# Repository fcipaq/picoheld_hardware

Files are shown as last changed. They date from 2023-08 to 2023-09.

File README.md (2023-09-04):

# Pico Held hardware files

Here you can find the PCB design files, BOM and CPL files, STL files of the case, schematics, components and datasheets for the *Pico Held* - a handheld based on the *Raspberry Pi Pico*.

The hardware project is released under the *Creative Commons NonCommercial license* (BY-NC, non-commercial use).

I am currently still looking for a distributor, so currently the only way to get a *Pico Held* is making your own PCB and case.

## Disclaimer

Please note (as also stated in the liscense): This design and all the files provided come without any warranty. I cannot be held responsible for any damage that might be caused. You build/operate at your own risk.

## Instruction video

This [Youtube](https://youtu.be/bDk0hH1kbgg) video demonstrates how to assemble the *Pico Held*.

## Case

I had the cases printed over at *JLCPCB* (no affiliation) using resin printing with - in my eyes - a very good result.

## PCB production parameters

Some notes for PCB production:

PCB thickness needs to be 1.2 mm (this is important for proper button haptics). Vias need to be untented for the recovery mechanism on the back to work. (Short the exposed via on the back side to ground when turning on the *Pico Held* to force bootloader mode).
Also, choosing "HASL leadfree" is definitely advised.

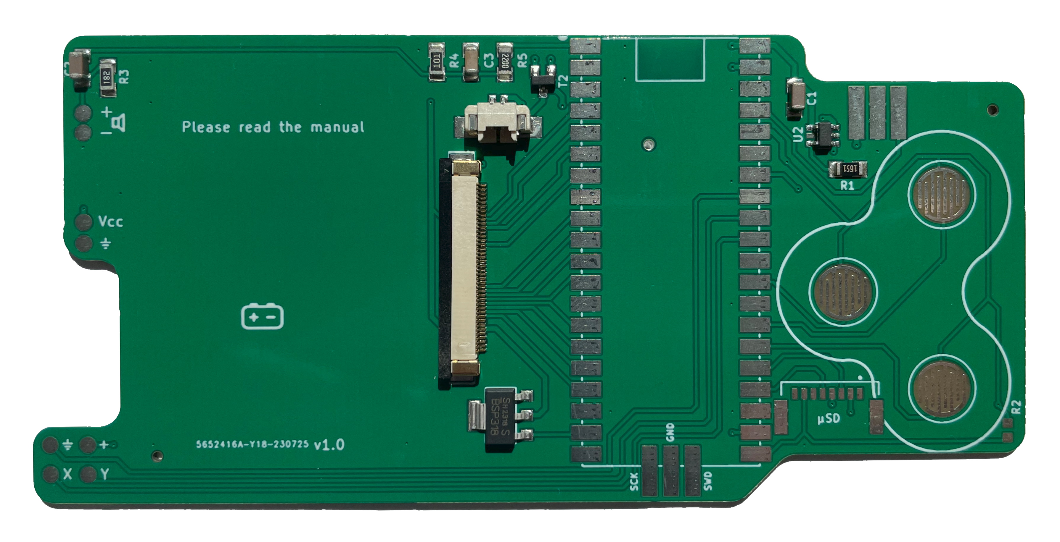
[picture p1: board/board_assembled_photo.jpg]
PCB assembled


## Parts sources

Here is where I sourced some of the parts (no affiliation):

µSD card slot:
aliexpress.com/item/32892777587.html

audio board:
aliexpress.com/item/1005002097528890.html

LCD (choose "3.2 NO TOUCH 40P"):
aliexpress.com/item/1005004769761714.html

speaker:
aliexpress.com/item/4001277480820.html

analog stick:
Any for the PSP1000 will do fine.

RPi Pico:
Both a "regular RPi Pico" as well as a "Waveshare RP2040-Plus" will fit.

## Support

If you like my work and would like to support me you might want to consider buying me a coffee :)

  

(Image by github.com/andreostrovsky -- Thanks!)

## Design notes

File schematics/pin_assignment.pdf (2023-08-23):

Pico Pin | LCD 0 | Audio | 1 | NC | LCD internal connection: 1 | 2 | NC | 5, 16, 37 2 | LCD_TE | 3 | NC 3 | LCD_RS (DC) | 4 | NC 4 | LCD_WR (CLK) | 5 | GND 5 | LCD_RESET | 6 | VCC 6 | LCD_DB8 | 7 | VCC 7 | LCD_DB9 | 8 | LCD_TE 8 | LCD_DB10 | 9 | CS (GND) 9 | LCD_DB11 | 10 | RS
10 | LCD_DB12 | 11 | CLK/WR
11 | LCD_DB13 | 12 | RD (VCC)
12 | LCD_DB14 | 13 | SPI_CLK (VCC)
13 | LCD_DB15 | 14 | NC
14 | LCD_LED (PWM) | 15 | Reset
15 | | 16 | GND
16 | SD_MISO | 17-24 | DB0 - DB7 (NC)
17 | SD_CS | 25 | DB8 (6)
18 | SD_SCK | 26 | DB9 (7)
19 | SD_MOSI | 27 | DB10 (8)
20 | BUTTON_3 | 28 | DB11 (9)
21 | BUTTON_1 | 29 | DB12 (10)
22 | BUTTON_2 | 30 | DB13 (11)
23 | - | 31 | DB14 (12)
24 | VBUS sense | 32 | DB15 (13)
25 | Onboard LED | 33 | LED+ (VCC)
26 | AnalogX | 34 | LED- (GND)
27 | AnalogY | 35 | LED- (GND)
28 | charger sense | 36 | LED- (GND)
29 | ADC VSYS | 37 | GND

### 38 IM0 (VCC) 39 IM1 (GND) 40 IM2 (GND)

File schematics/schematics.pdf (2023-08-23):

# Pico Held schematics

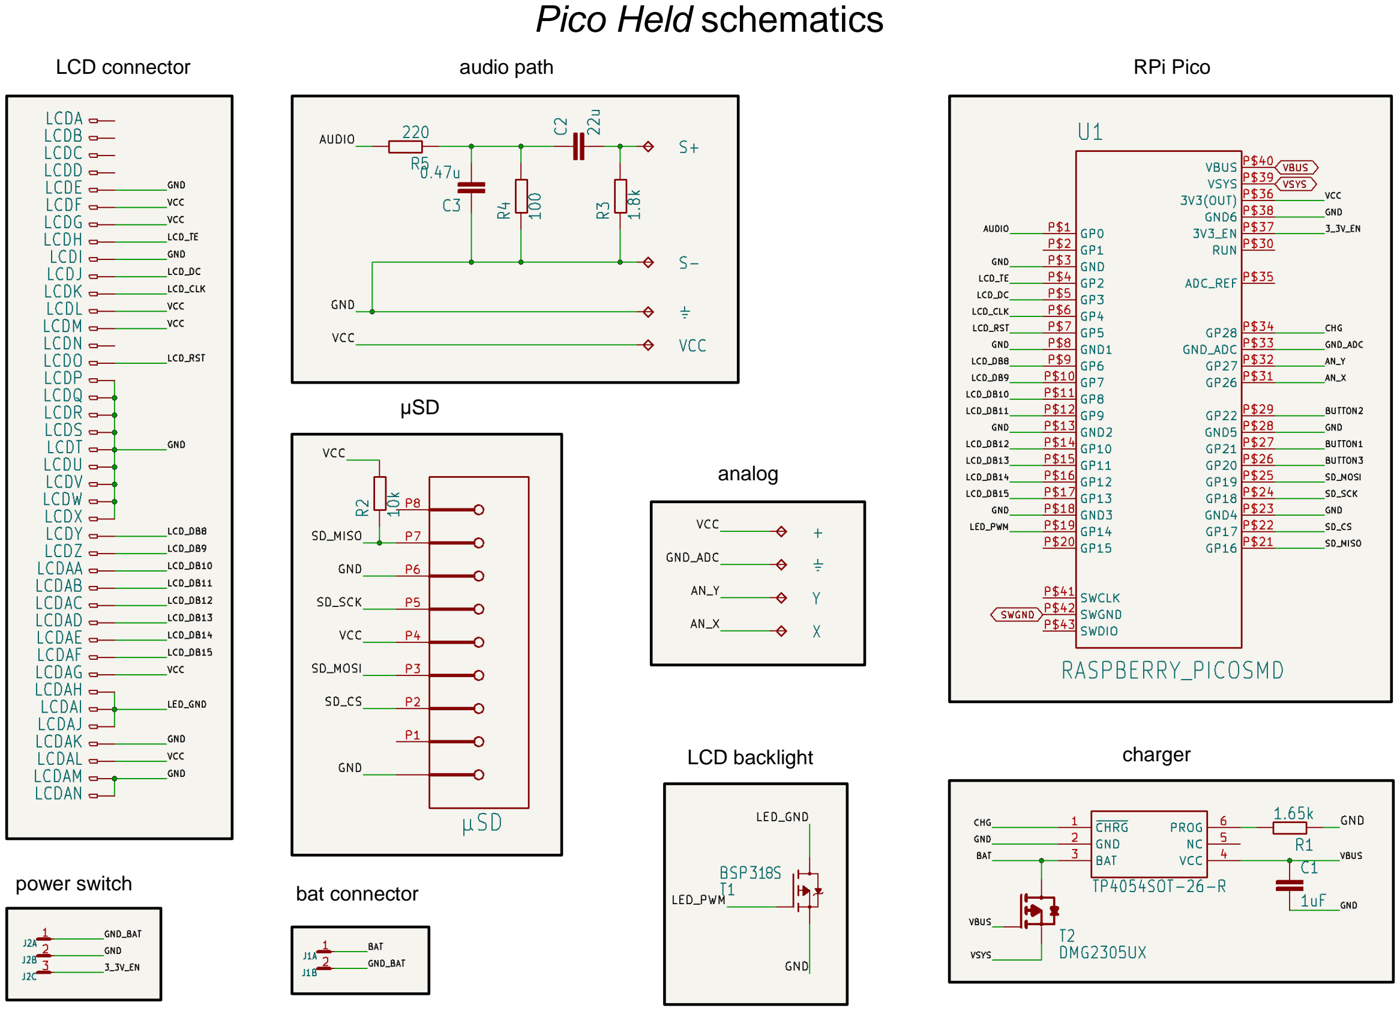
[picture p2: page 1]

LCD connector

charger

RPi Pico

LCD backlight

audio path

analog

μSD

power switch | bat connector

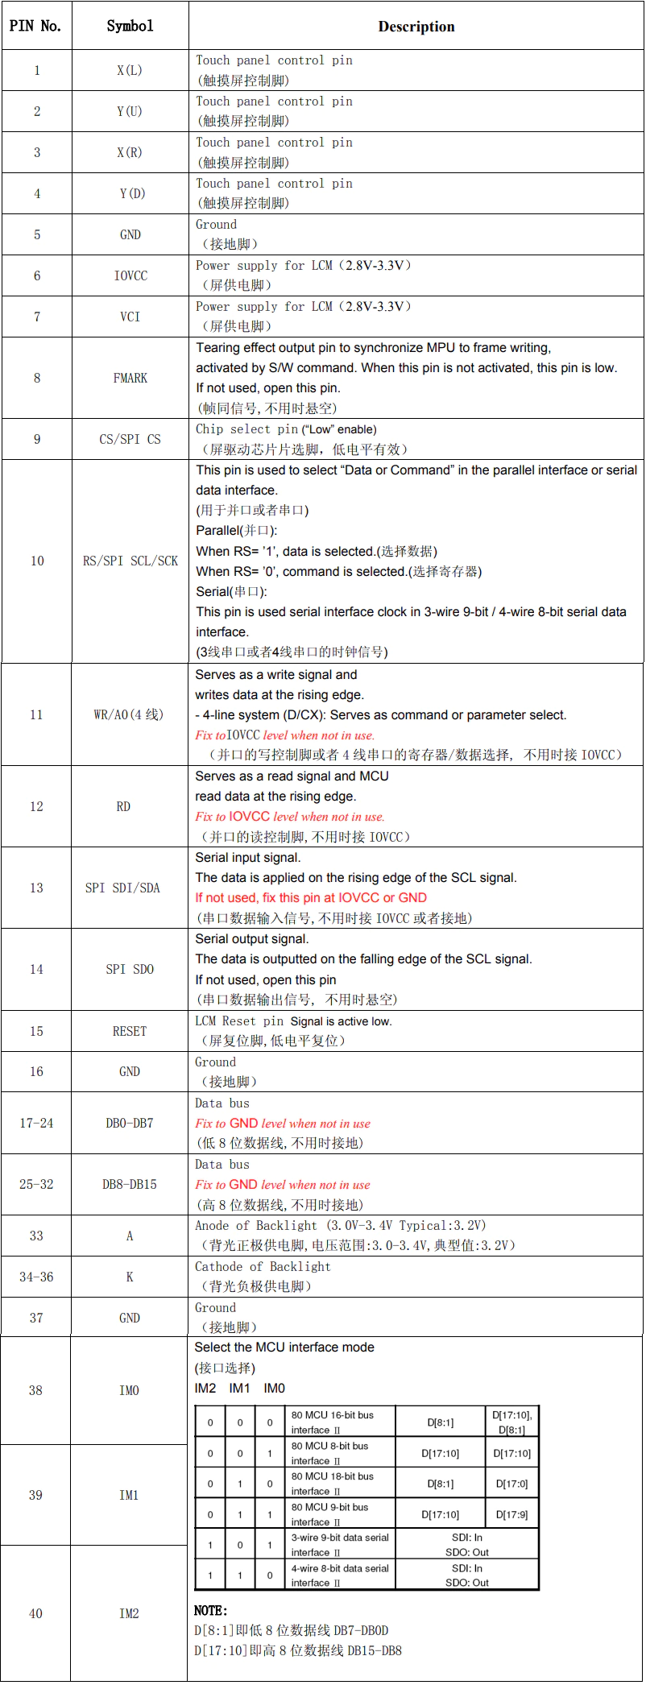
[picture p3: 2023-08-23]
datasheets/LCD/pinout.png

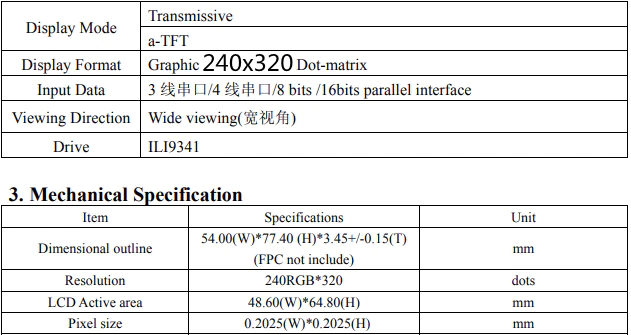
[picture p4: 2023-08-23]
datasheets/LCD/dimension2.png

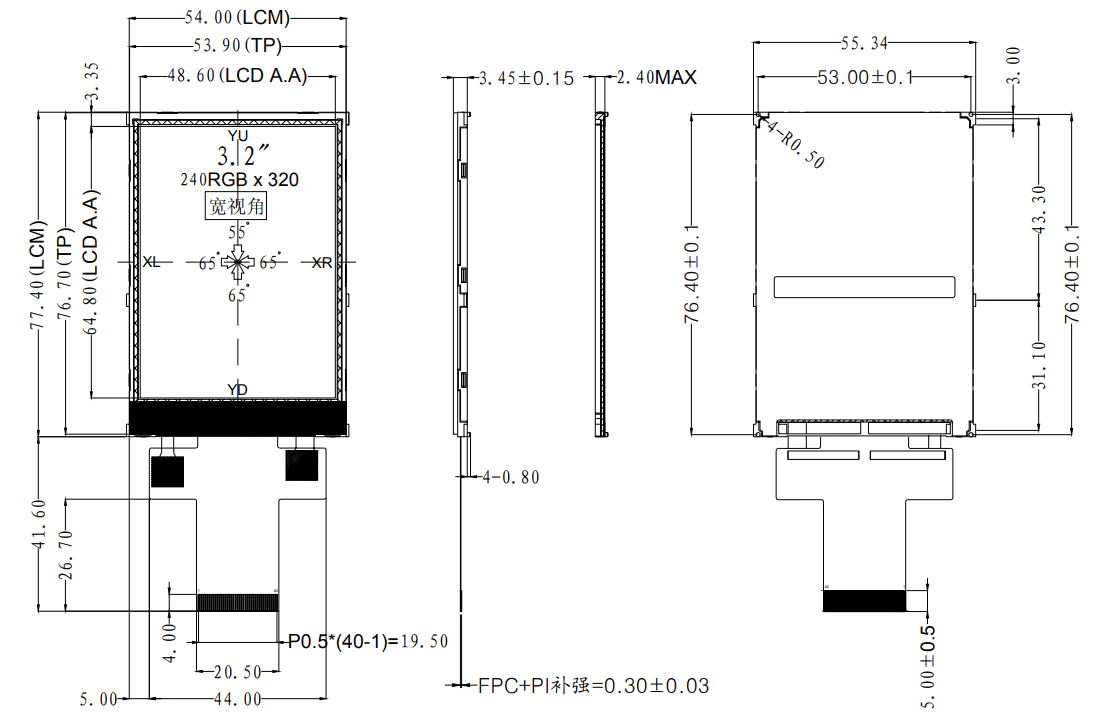
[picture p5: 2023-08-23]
datasheets/LCD/dimensions1.png

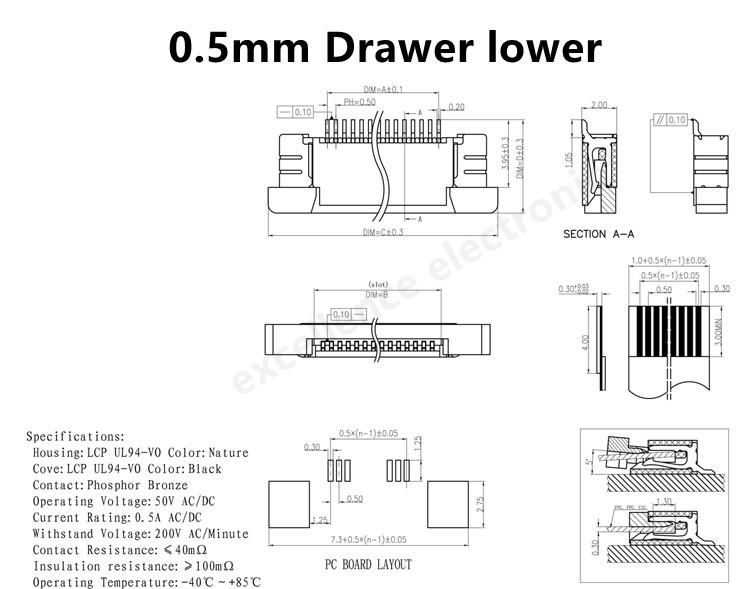
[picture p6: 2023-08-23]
datasheets/LCD_con/lcd connector.jpg

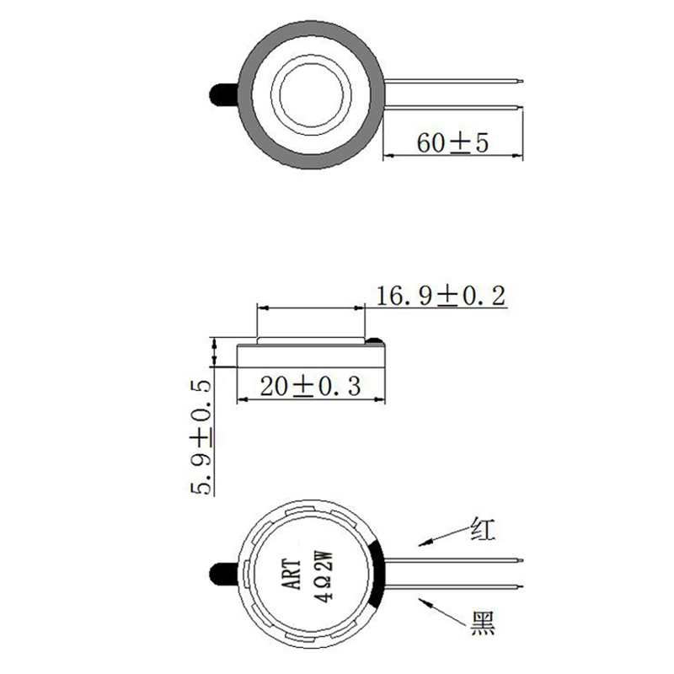
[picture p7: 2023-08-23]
datasheets/speaker/speaker.jpg

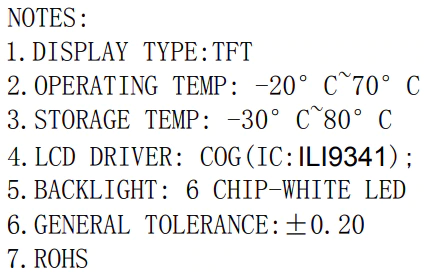
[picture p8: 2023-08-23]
datasheets/LCD/ratings.png

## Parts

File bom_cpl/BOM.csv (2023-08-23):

Comment | Designator | Footprint | JLCPCB Part #
1 uF | C1 | C1206 | C91151
22 uF | C2 | C1206 | C968784
470 nF | C3 | C1206 | C282872
SM02B-SRSS-TB | J1 | SM02B-SRSS-TB | C2939411
FH12-40S-0.5SH | LCD | FH12-40S-0.5SH | C247827
1.65k | R1 | R1206 | C332962
1.8k | R3 | R1206 | C384013
100 | R4 | R1206 | C118845
220 | R5 | R1206 | C104696
BSP318P | T1 | PG-SOT-223 | C135808
DMG2305UX | T2 | SOT23 | C150470
TP4054SOT-26-R | U2 | SOT23-6 | C382138
MOLEX_47309-2651 | µSD | MOLEX_47309-2651_0 | C587826

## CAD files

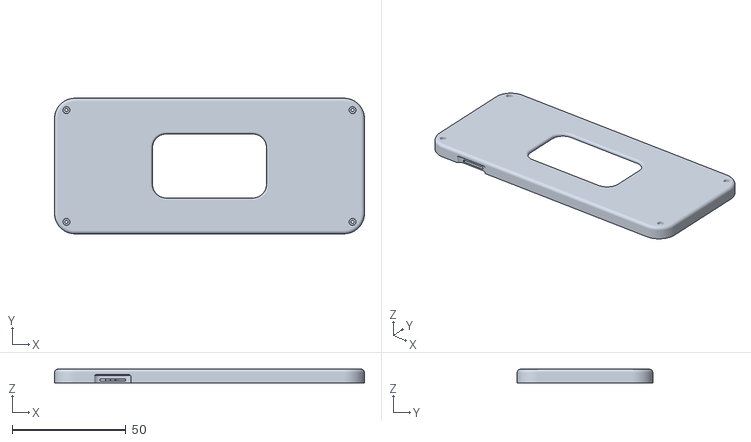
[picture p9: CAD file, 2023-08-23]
case/bottom.stl
136.0 x 59.5 x 6.00

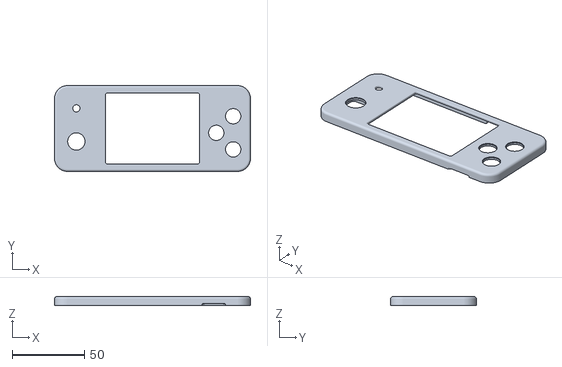
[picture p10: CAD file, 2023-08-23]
case/top.stl
136.0 x 59.5 x 6.00

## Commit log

2023-08-23 Add PCB image
2023-09-04 Add assembly video
